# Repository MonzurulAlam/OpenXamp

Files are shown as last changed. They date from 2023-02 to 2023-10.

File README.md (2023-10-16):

# OpenExoAmp
Bio-signal Amplifier

### OBJECTIVES:
<P align="justify"> The objective of this project is to develop a bio-signal amplifier for sensing physiological signals.

### DESCRIPTION:
<P align="justify"> Block diagram of an amplifier (OpenExoAmp) for bio-signal amplification and filtering. The amplifier is built with commercially-off-the-shelf components and powered by a pair of batteries. A pre-amplifier section with high common-mode-rejection-ratio (CMRR) is used to differencially pick the bio-signal. If differential input is not required, the inverting input can be shorted with the input reference terminal. The signal is then band-passed filtered and amplified to the desired value by controlling the gain of the amplifier. One can directly use this analog signal or digitised by an analog-t-digital converter (ADC) and a a microcontroller (MCU). The digitised signal can be transfered to a computer via serial network (USB). Note that many MCU boards have built-in ADC and USB interfaces that can be used for the ditisation of the amplified bio-signal. 

Block-Diagram

### DISCLAIMER:
<P align="justify"> The design is offered as it is. Although it has been regorously tested with utmost care and to the best of my knowledge, I do not provide any warranty in any aspect.

### WARNING:
- The design is intended stricktly for research and education purposes.
- The stimulator is not approved for human or animal use without receving prior approval from a local ethics committee such as Institutional Review Board.

### LICENSE:
##### Documentation licensed under the Creative Commons Attribution Share Alike 4.0 International License

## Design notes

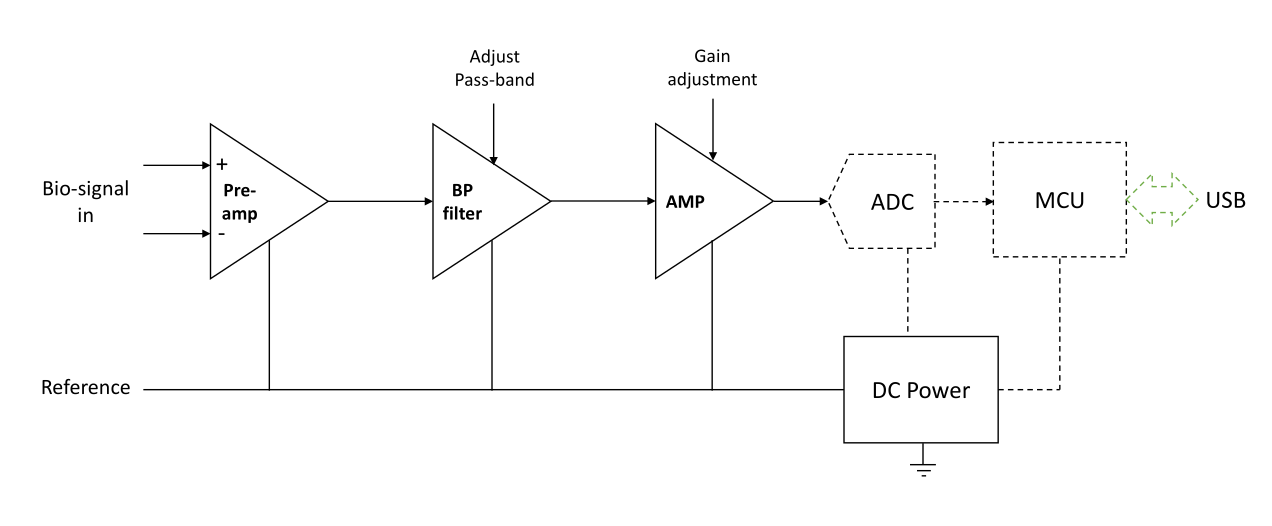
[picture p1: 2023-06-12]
BlockDiagram.png

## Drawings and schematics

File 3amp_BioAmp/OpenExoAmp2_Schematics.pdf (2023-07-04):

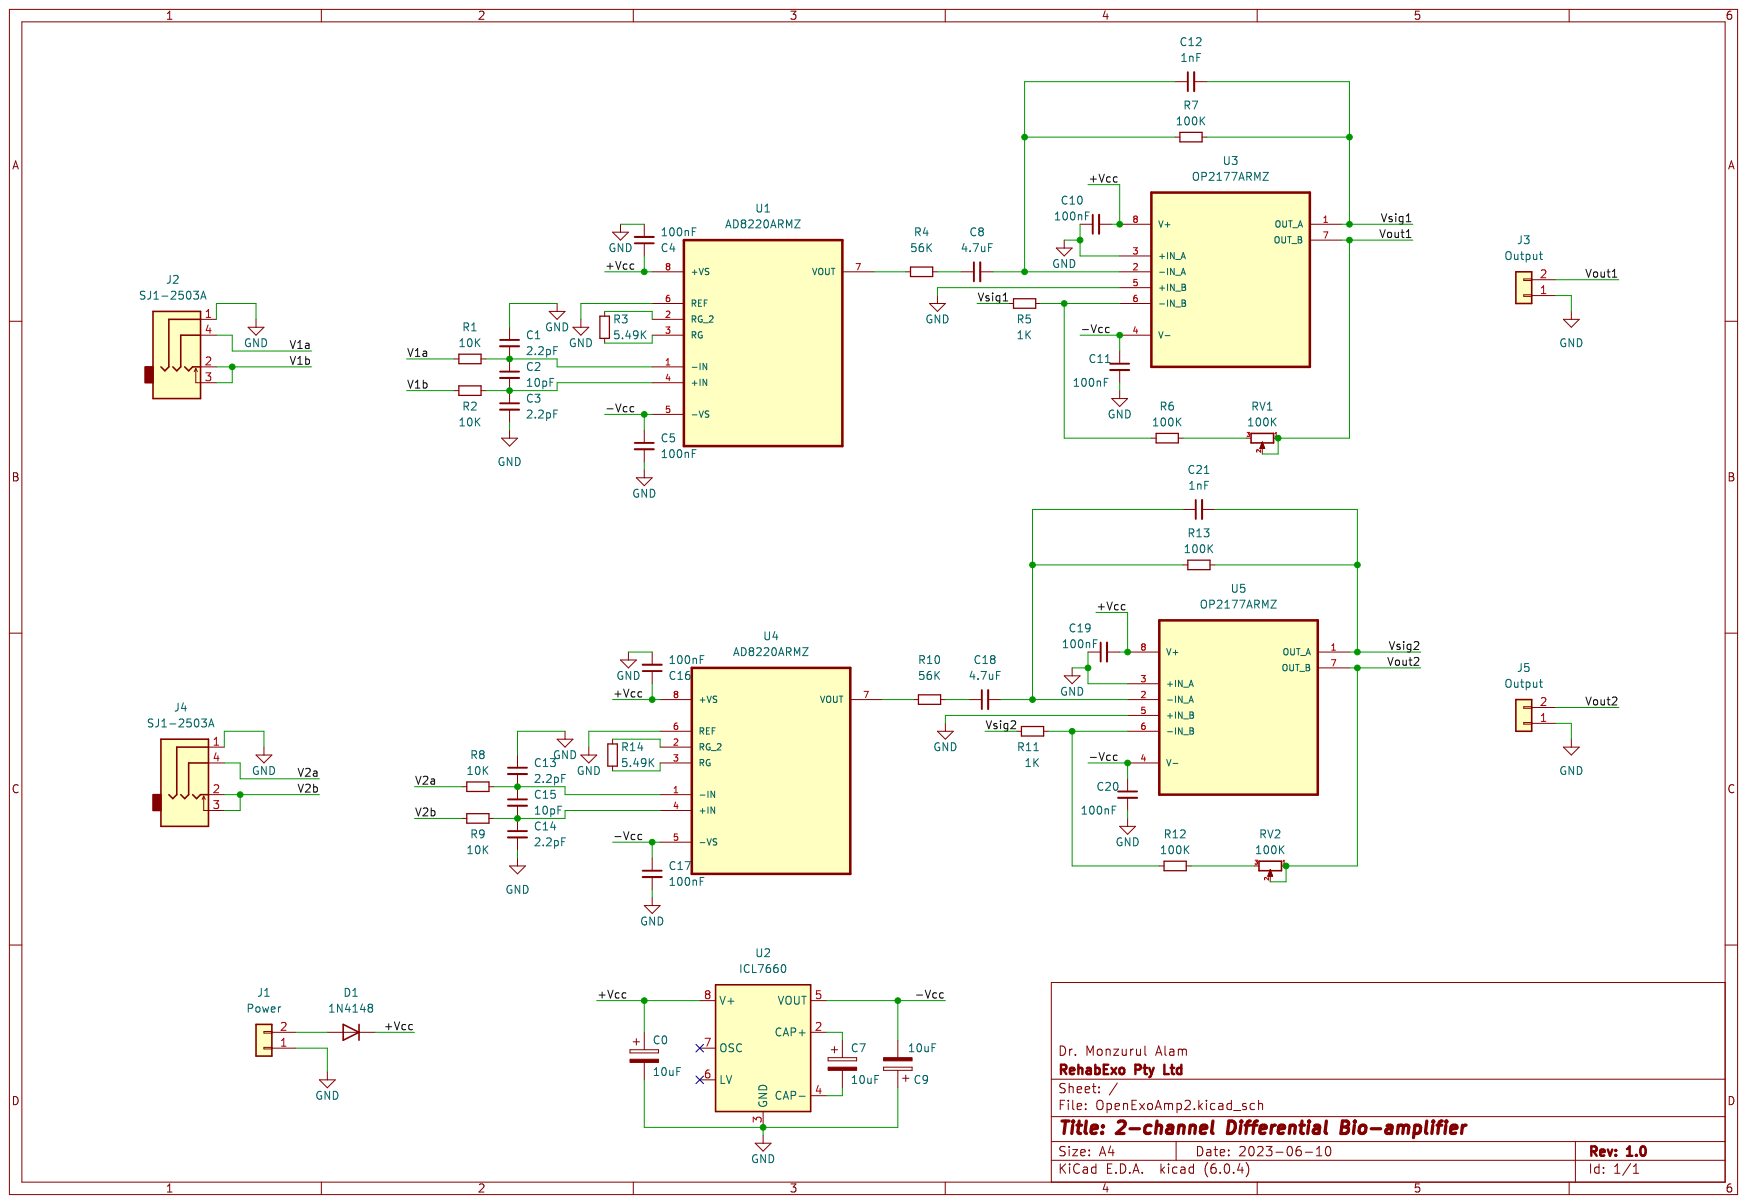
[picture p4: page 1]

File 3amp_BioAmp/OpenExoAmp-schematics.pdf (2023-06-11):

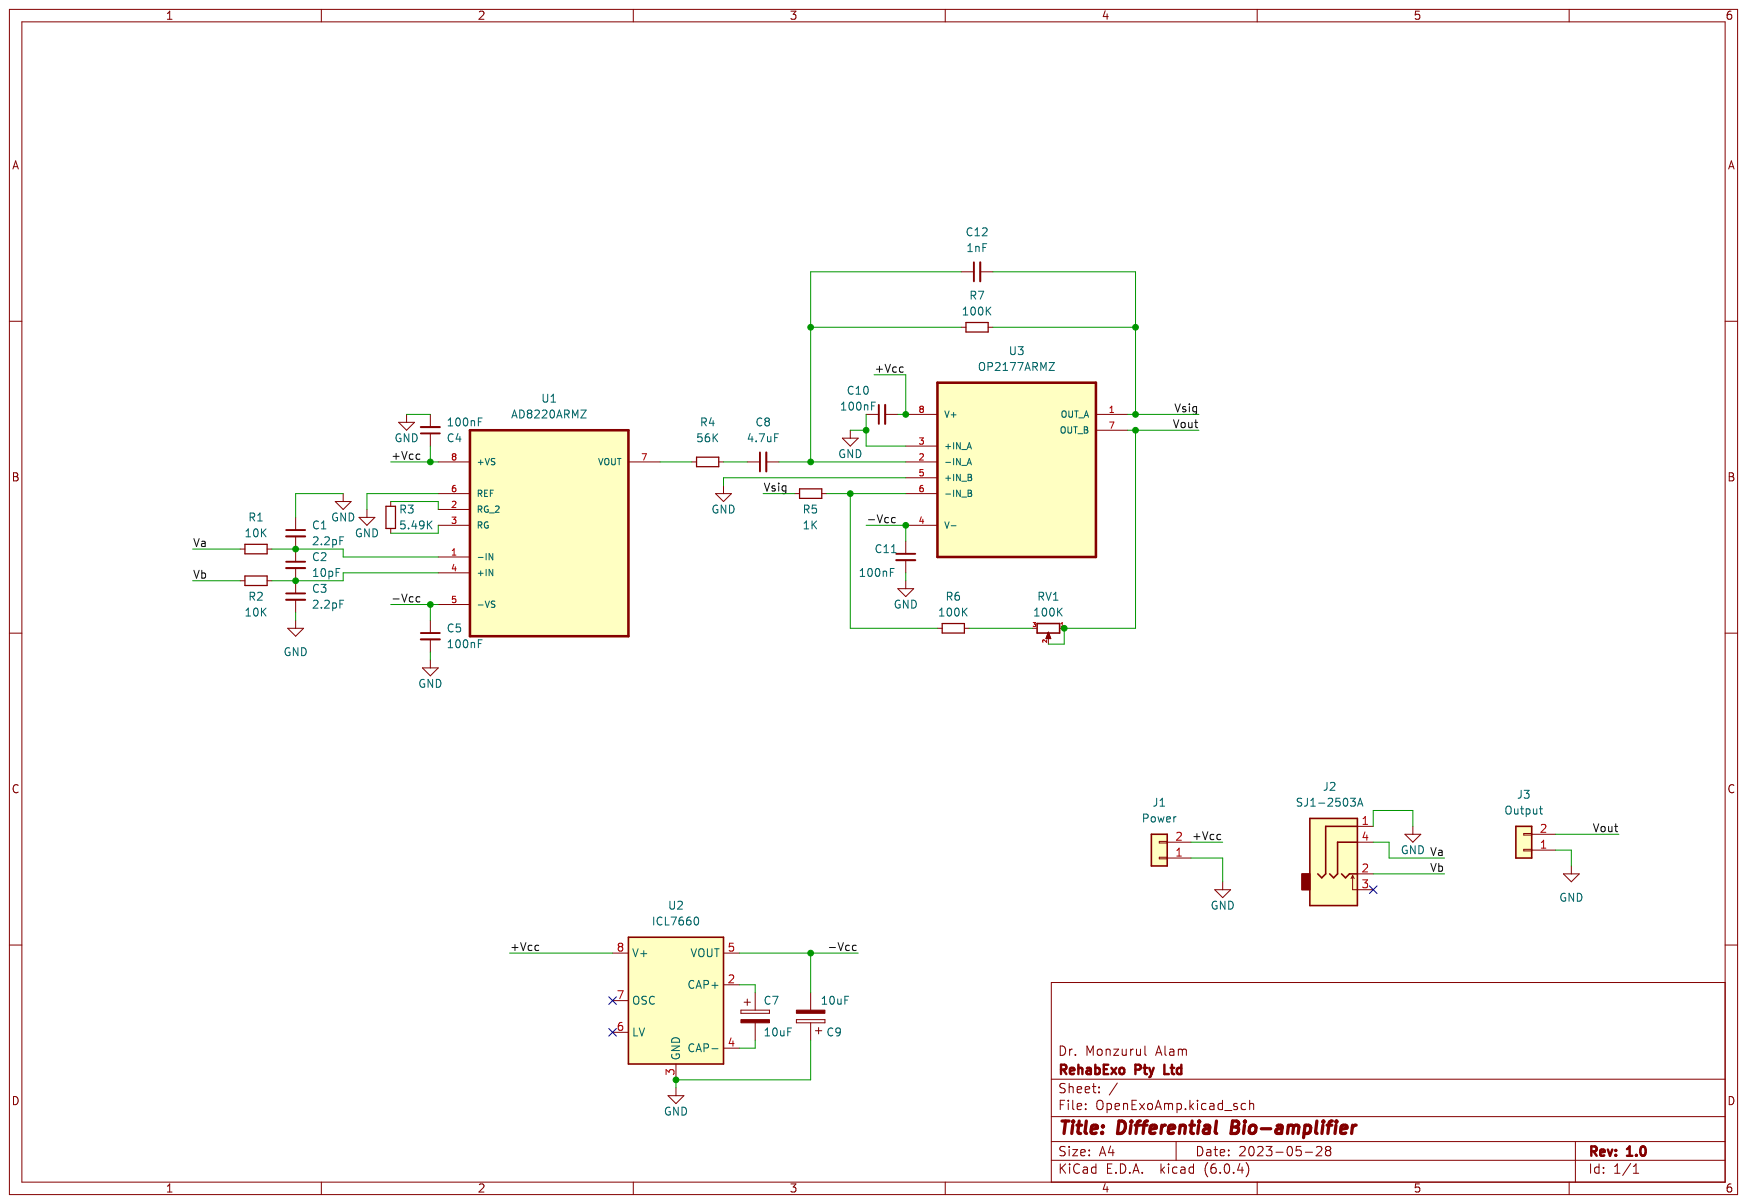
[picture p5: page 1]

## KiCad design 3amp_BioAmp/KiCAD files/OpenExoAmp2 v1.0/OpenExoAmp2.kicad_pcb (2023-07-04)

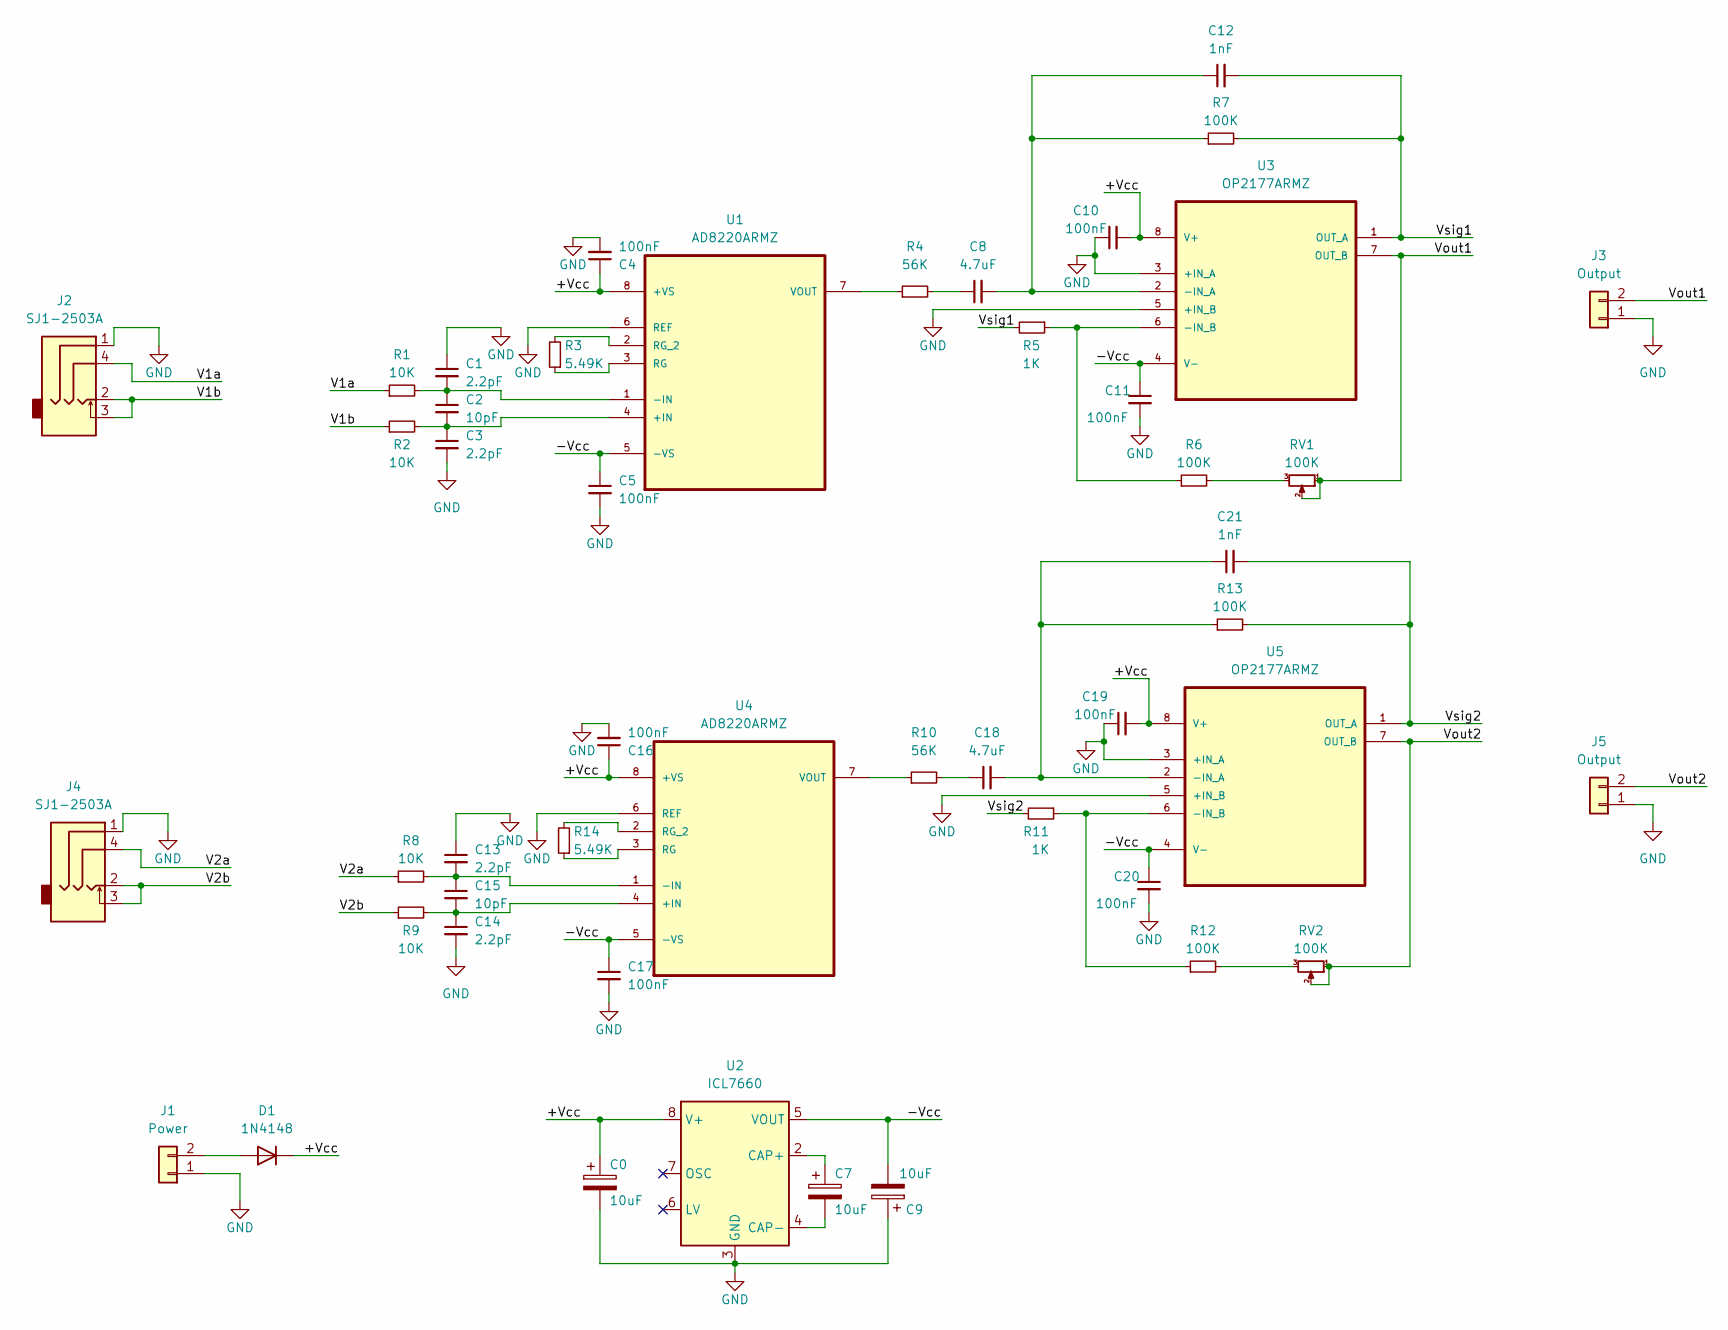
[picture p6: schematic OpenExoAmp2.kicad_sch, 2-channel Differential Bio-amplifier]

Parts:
C0, C7, C9: 10uF; C_1206_3216Metric
C1, C3, C13, C14: 2.2pF; C_0603_1608Metric
C2, C15: 10pF; C_0603_1608Metric
C4, C5, C10, C11, C16, C17, C19, C20: 100nF; C_0603_1608Metric
C8, C18: 4.7uF; C_0603_1608Metric
C12, C21: 1nF; C_0603_1608Metric
D1: 1N4148; D_SOD-123
J1: Power; JST_PH_B2B-PH-K_1x02_P2.00mm_Vertical
J2, J4: SJ1-2503A; CUI_SJ1-2503A
J3, J5: Output; PinHeader_1x02_P2.54mm_Vertical
R1, R2, R8, R9: 10K; R_0603_1608Metric
R3, R14: 5.49K; R_0603_1608Metric
R4, R10: 56K; R_0603_1608Metric
R5, R11: 1K; R_0603_1608Metric
R6, R7, R12, R13: 100K; R_0603_1608Metric
RV1, RV2: 100K; TRIM_TC33X-2-104E
U1, U4: AD8220ARMZ; MSOP-8_3x3mm_P0.65mm; MPN AD8220ARMZ
U2: ICL7660; SOIC-8_3.9x4.9mm_P1.27mm
U3, U5: OP2177ARMZ; MSOP-8_3x3mm_P0.65mm; MPN OP2177ARMZ

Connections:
/+Vcc: C0.1, C4.1, C10.2, C16.1, C19.2, D1.1 (K), U1.8 (+VS), U2.8 (V+), U3.8 (V+), U4.8 (+VS), U5.8 (V+)
/-Vcc: C5.1, C9.2, C11.1, C17.1, C20.1, U1.5 (-VS), U2.5 (VOUT), U3.4 (V-), U4.5 (-VS), U5.4 (V-)
/V1a: J2.4, R1.1
/V1b: J2.2, J2.3, R2.1
/V2a: J4.4, R8.1
/V2b: J4.2, J4.3, R9.1
/Vout1: J3.2, RV1.1, RV1.2, U3.7 (OUT_B)
/Vout2: J5.2, RV2.1, RV2.2, U5.7 (OUT_B)
/Vsig1: C12.2, R5.2, R7.2, U3.1 (OUT_A)
/Vsig2: C21.2, R11.2, R13.2, U5.1 (OUT_A)
GND: C0.2, C1.1, C3.2, C4.2, C5.2, C9.1, C10.1, C11.2, C13.1, C14.2, C16.2, C17.2, C19.1, C20.2, J1.1, J2.1, J3.1, J4.1, J5.1, U1.6 (REF), U2.3 (GND), U3.3 (+IN_A), U3.5 (+IN_B), U4.6 (REF), U5.3 (+IN_A), U5.5 (+IN_B)
unnamed: C1.2, C2.1, R1.2, U1.1 (-IN)
unnamed: C2.2, C3.1, R2.2, U1.4 (+IN)
unnamed: C7.1, U2.2 (CAP+)
unnamed: C7.2, U2.4 (CAP-)
unnamed: C8.1, R4.2
unnamed: C8.2, C12.1, R7.1, U3.2 (-IN_A)
unnamed: C13.2, C15.1, R8.2, U4.1 (-IN)
unnamed: C14.1, C15.2, R9.2, U4.4 (+IN)
unnamed: C18.1, R10.2
unnamed: C18.2, C21.1, R13.1, U5.2 (-IN_A)
unnamed: D1.2 (A), J1.2
unnamed: R3.1, U1.3 (RG)
unnamed: R3.2, U1.2 (RG_2)
unnamed: R4.1, U1.7 (VOUT)
unnamed: R5.1, R6.1, U3.6 (-IN_B)
unnamed: R6.2, RV1.3
unnamed: R10.1, U4.7 (VOUT)
unnamed: R11.1, R12.1, U5.6 (-IN_B)
unnamed: R12.2, RV2.3
unnamed: R14.1, U4.3 (RG)
unnamed: R14.2, U4.2 (RG_2)

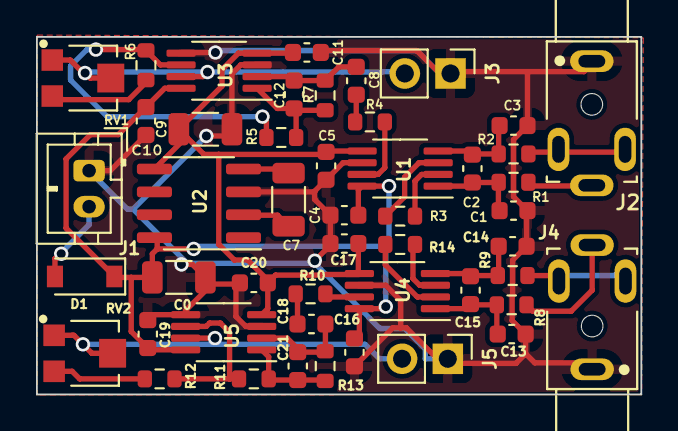
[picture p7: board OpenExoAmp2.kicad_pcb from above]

Board: 2 copper layers, 33.6 x 19.9 mm, 48 parts (0 on the bottom side), 32 nets.
